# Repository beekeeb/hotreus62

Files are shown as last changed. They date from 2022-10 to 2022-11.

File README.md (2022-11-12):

# Hotreus62 Keyboard

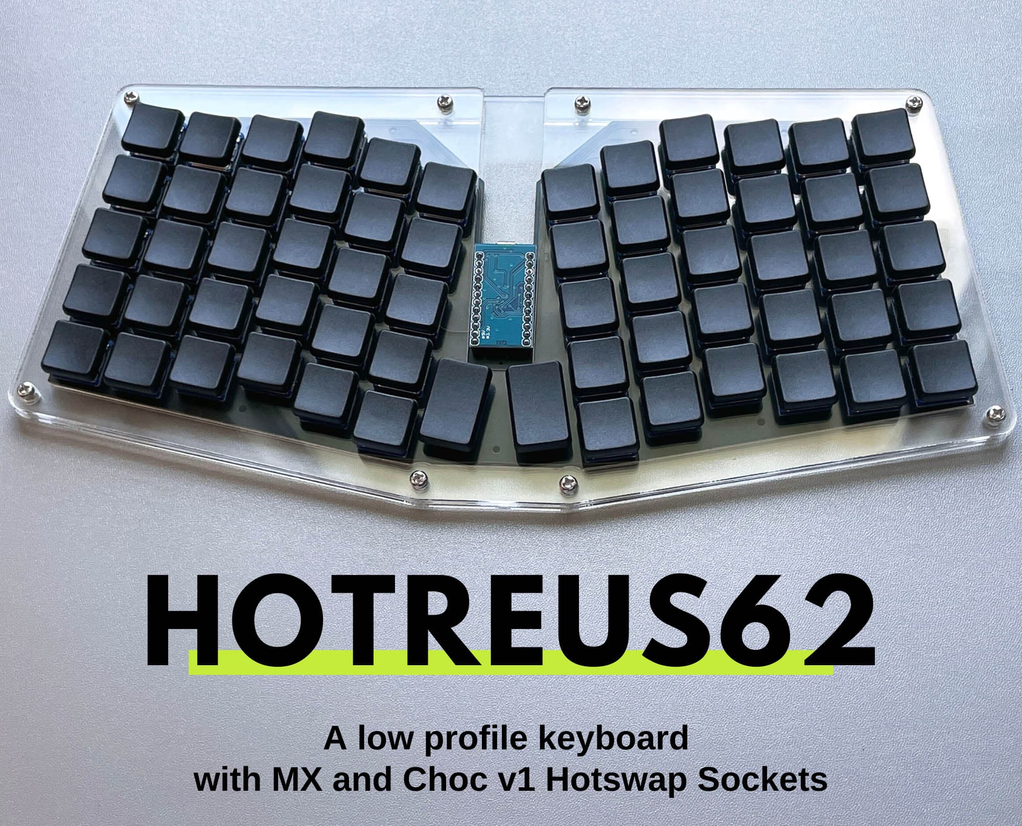
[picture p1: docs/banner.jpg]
Hotreus62 Keyboard


The Hotreus62 Keyboard is a fork of [atreus62 keyboard](https://github.com/profet23/atreus62). It supports MX hotswap and Kailh Choc v1 hotswap sockets on the same board, similar to [Lily58 Pro](https://github.com/kata0510/Lily58). It's great for testing which type of keyswitches feels best for the keyboard. The overall keyboard height is reduced, with the breakout board placing on the top.

More photos can be found at the [beekeeb showcase](https://showcase.beekeeb.com/hotreus62-hotswap/).
Pre-soldered keyboard PCBs / DIY kits are available at the [beekeeb shop](https://shop.beekeeb.com/?s=hotreus62&post_type=product).

## Features
- 62 keys: enough keys for having a number row.
- Dual Hotswap Sockets: Support both Kailh Choc (low profile) / MX hotswap sockets on the same board.
- Lower profile: The overall keyboard height is reduced, with the breakout board placing on the top.

## Bill of Materials (BOM)

Qty | Item 
--- | --- 
1 | Hotreus62 PCB
1 | Micro controller (Pro-micro or equivalent)
2 | Pins and sockets for the controller (12 pin)
62 | 1N4148 SOD-123 diodes
62 | hotswap sockets (mx or/and choc v1)
62 | mx keycaps or choc v1 low profile keycaps

## Case

A stacked acrylic case design is available in `case` folder.
For the switch plate, when acrylic plates are used, 2mm (choc) or 3mm (MX) is recommended.
When metal or carbon fiber plates are used, 1.2mm (choc) or 1.5mm (MX) is recommended.

## Firmware

An example for the Vial firmware can be found at https://github.com/beekeeb/vial-qmk-hotreus62

## TODO
- Add a photo build log

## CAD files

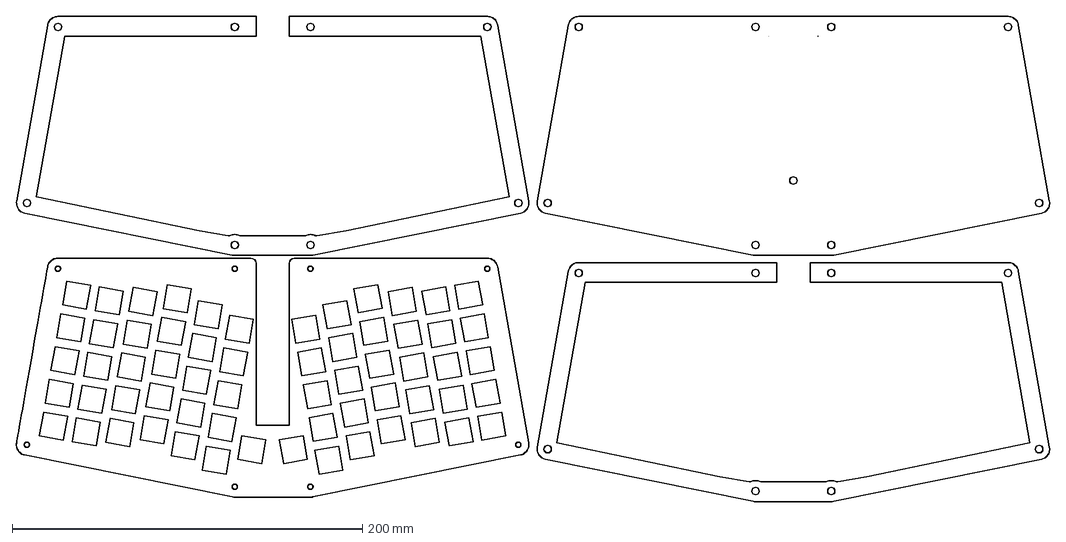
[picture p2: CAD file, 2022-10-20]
case/stack-acrylic-with-kerf.dxf
590.2 x 277.2 mm

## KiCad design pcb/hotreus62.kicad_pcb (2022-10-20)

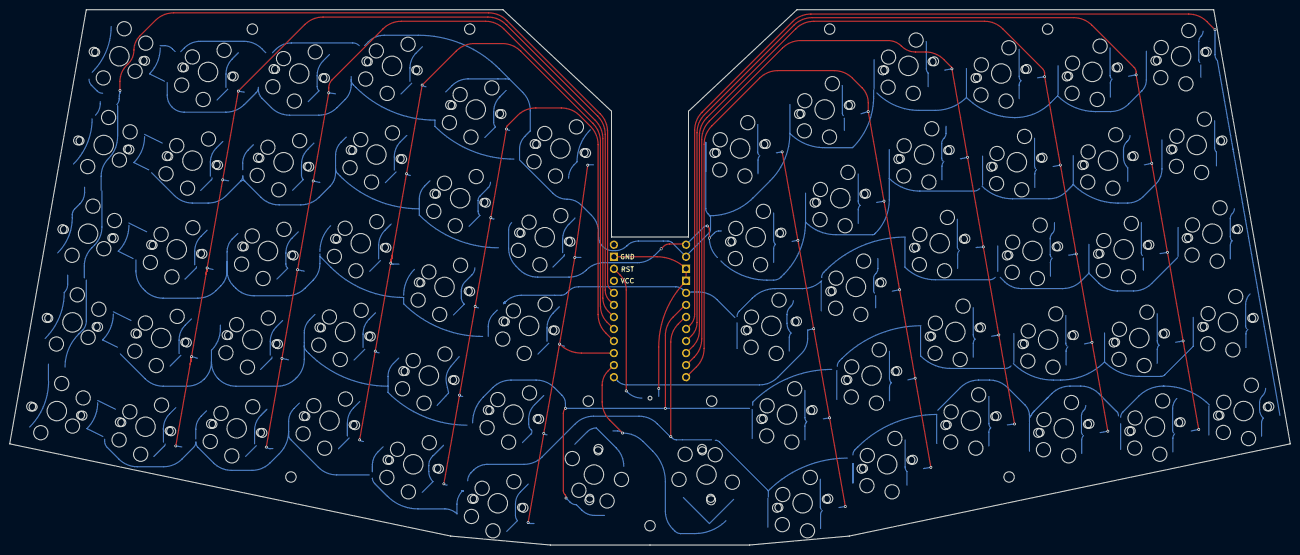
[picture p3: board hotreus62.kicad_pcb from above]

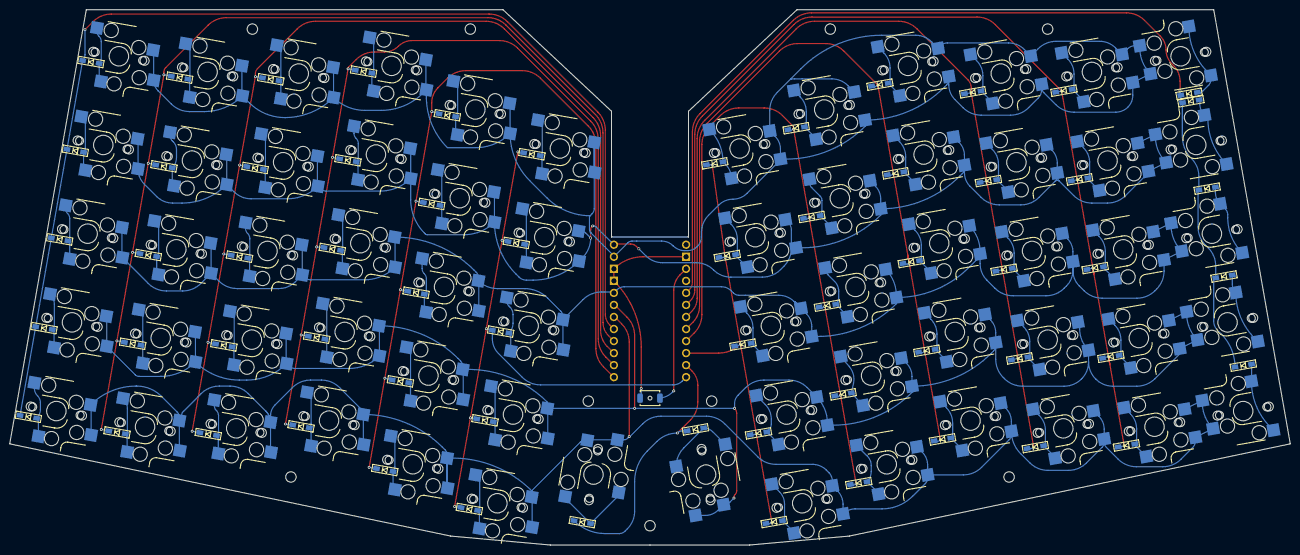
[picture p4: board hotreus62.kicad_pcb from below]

Board: 2 copper layers, 270.1 x 112.9 mm, 126 parts (64 on the bottom side), 82 nets.

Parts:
D1, D2, D3, D4, D5, D6, D7, D8, D9, D10, D11, D12, D13, D14, D15, D16, D17, D18, D19, D20, D21, D22, D23, D24, D25, D26, D27, D28, D29, D30, D31, D32, D33, D34, D35, D36, D37, D38, D39, D40, D41, D42, D43, D44, D45, D46, D47, D48, D49, D50, D51, D52, D53, D54, D55, D56, D57, D58, D59, D60, D61, D62: DIODE; atreus-D3_SMD_v2
SW1, SW2, SW3, SW4, SW5, SW6, SW7, SW8, SW9, SW10, SW11, SW12, SW13, SW14, SW15, SW16, SW17, SW18, SW19, SW20, SW21, SW22, SW23, SW24, SW25, SW26, SW27, SW28, SW29, SW30, SW31, SW32, SW33, SW34, SW35, SW36, SW37, SW38, SW39, SW40, SW41, SW42, SW43, SW44, SW45, SW46, SW47, SW48, SW49, SW50, SW51, SW52, SW53, SW54, SW55, SW56, SW57, SW58, SW59, SW60, SW61, SW62: SWITCH_PUSH; hotswap_mx_choc
SW-RST1: SWITCH_PUSH; SW_Push_4x2
U1: ARDUINO_PRO_MICRO

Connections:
/COL0: D1.2, D2.2, D3.2, D4.2, D5.2, U1.20
/COL1: D6.2, D7.2, D8.2, D9.2, D10.2, U1.19
/COL2: D11.2, D12.2, D13.2, D14.2, D15.2, U1.18
/COL3: D16.2, D17.2, D18.2, D19.2, D20.2, U1.17
/COL4: D21.2, D22.2, D23.2, D24.2, D25.2, U1.16
/COL5: D26.2, D27.2, D28.2, D29.2, D30.2, U1.15
/COL6: D31.2, D32.2, U1.14
/COL7: D33.2, D34.2, D35.2, D36.2, D37.2, U1.13
/COL8: D38.2, D39.2, D40.2, D41.2, D42.2, U1.12
/COL9: D43.2, D44.2, D45.2, D46.2, D47.2, U1.11
/COL10: D48.2, D49.2, D50.2, D51.2, D52.2, U1.10
/COL11: D53.2, D54.2, D55.2, D56.2, D57.2, U1.9
/COL12: D58.2, D59.2, D60.2, D61.2, D62.2, U1.8
/ROW0: SW5.1, SW10.1, SW15.1, SW20.1, SW25.1, SW30.1, SW32.1, SW37.1, SW42.1, SW47.1, SW52.1, SW57.1, SW62.1, U1.7
/ROW1: SW4.1, SW9.1, SW14.1, SW19.1, SW24.1, SW29.1, SW31.1, SW36.1, SW41.1, SW46.1, SW51.1, SW56.1, SW61.1, U1.6
/ROW2: SW3.1, SW8.1, SW13.1, SW18.1, SW23.1, SW28.1, SW35.1, SW40.1, SW45.1, SW50.1, SW55.1, SW60.1, U1.5
/ROW3: SW2.1, SW7.1, SW12.1, SW17.1, SW22.1, SW27.1, SW34.1, SW39.1, SW44.1, SW49.1, SW54.1, SW59.1, U1.1
/ROW4: SW1.1, SW6.1, SW11.1, SW16.1, SW21.1, SW26.1, SW33.1, SW38.1, SW43.1, SW48.1, SW53.1, SW58.1, U1.2
GND: SW-RST1.1, U1.3, U1.4, U1.23
unnamed: D1.1, SW1.2
unnamed: D2.1, SW2.2
unnamed: D3.1, SW3.2
unnamed: D4.1, SW4.2
unnamed: D5.1, SW5.2
unnamed: D6.1, SW6.2
unnamed: D7.1, SW7.2
unnamed: D8.1, SW8.2
unnamed: D9.1, SW9.2
unnamed: D10.1, SW10.2
unnamed: D11.1, SW11.2
unnamed: D12.1, SW12.2
unnamed: D13.1, SW13.2
unnamed: D14.1, SW14.2
unnamed: D15.1, SW15.2
unnamed: D16.1, SW16.2
unnamed: D17.1, SW17.2
unnamed: D18.1, SW18.2
unnamed: D19.1, SW19.2
unnamed: D20.1, SW20.2
unnamed: D21.1, SW21.2
unnamed: D22.1, SW22.2
unnamed: D23.1, SW23.2
unnamed: D24.1, SW24.2
unnamed: D25.1, SW25.2
unnamed: D26.1, SW26.2
unnamed: D27.1, SW27.2
unnamed: D28.1, SW28.2
unnamed: D29.1, SW29.2
unnamed: D30.1, SW30.2
unnamed: D31.1, SW31.2
unnamed: D32.1, SW32.2
unnamed: D33.1, SW33.2
unnamed: D34.1, SW34.2
unnamed: D35.1, SW35.2
unnamed: D36.1, SW36.2
unnamed: D37.1, SW37.2
unnamed: D38.1, SW38.2
unnamed: D39.1, SW39.2
unnamed: D40.1, SW40.2
unnamed: D41.1, SW41.2
unnamed: D42.1, SW42.2
unnamed: D43.1, SW43.2
unnamed: D44.1, SW44.2
unnamed: D45.1, SW45.2
unnamed: D46.1, SW46.2
unnamed: D47.1, SW47.2
unnamed: D48.1, SW48.2
unnamed: D49.1, SW49.2
unnamed: D50.1, SW50.2
unnamed: D51.1, SW51.2
unnamed: D52.1, SW52.2
unnamed: D53.1, SW53.2
unnamed: D54.1, SW54.2
unnamed: D55.1, SW55.2
unnamed: D56.1, SW56.2
unnamed: D57.1, SW57.2
unnamed: D58.1, SW58.2
unnamed: D59.1, SW59.2
unnamed: D60.1, SW60.2
unnamed: D61.1, SW61.2
unnamed: D62.1, SW62.2
unnamed: SW-RST1.2, U1.22

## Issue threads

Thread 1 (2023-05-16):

Holes at case not symmetrical. This is not Issue.

inot, 2023-05-16:
Hello, have no idea how to send you this information. This is not issue, just if someone will cut acrylic case, and stack all parts together, need to take attention for case slice position, probably you need to stack it upside-down.  Maybe you could add this tip at readme.

Closed 2023-05-16.
